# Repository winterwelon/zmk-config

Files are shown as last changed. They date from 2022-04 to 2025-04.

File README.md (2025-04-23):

<p align="center">
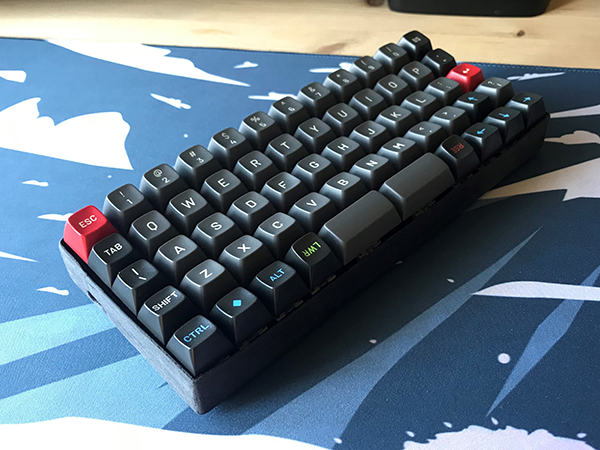
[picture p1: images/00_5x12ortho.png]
  
</p>

# Quick Summary

- :heavy_check_mark: 5x12 Ortholinear Keyboard
- :heavy_check_mark: Hotswappable
- :heavy_check_mark: Modular Spacebar 1x4u (57 keys) or 2x2u (58 keys)
- :heavy_check_mark: Wireless Bluetooth /w nice!nano running ZMK firmware

## Why?

I'm a clumsy man and I often hit the corner of my [96% keyboard](https://www.keychron.com/collections/96-layout-keyboards/products/keychron-k4-wireless-mechanical-keyboard-version-2) when I move my mouse.

So instead of doing the sensible thing and getting a TKL or smaller keyboard, I took the nuclear option of going straight into ortholinear keyboards (because I wanted one and to be honest, they look cool). 

There was a problem though. 

Of all the current 5x12 ortholinear keyboards on the market, I couldn't find one that was a) wireless and b) using a 1x4u spacebar or 2x2u spacebar setup. 

Either I wait for someone to make and sell it or I build it myself.

So... here I am, learning how to make it from the ground up over the course of a few months with no knowledge of pcb design and keyboard form factors. 

Here are some of the steps I've taken to make it.

#### PCB Design
- USB port on the left since it couldn't fit on the top
- Added a reset switch into the board for quick firmware flashing
<table>
  <tr>
    <td>Schematic</td>
     <td>Trace Routing</td>
  </tr>
  <tr>
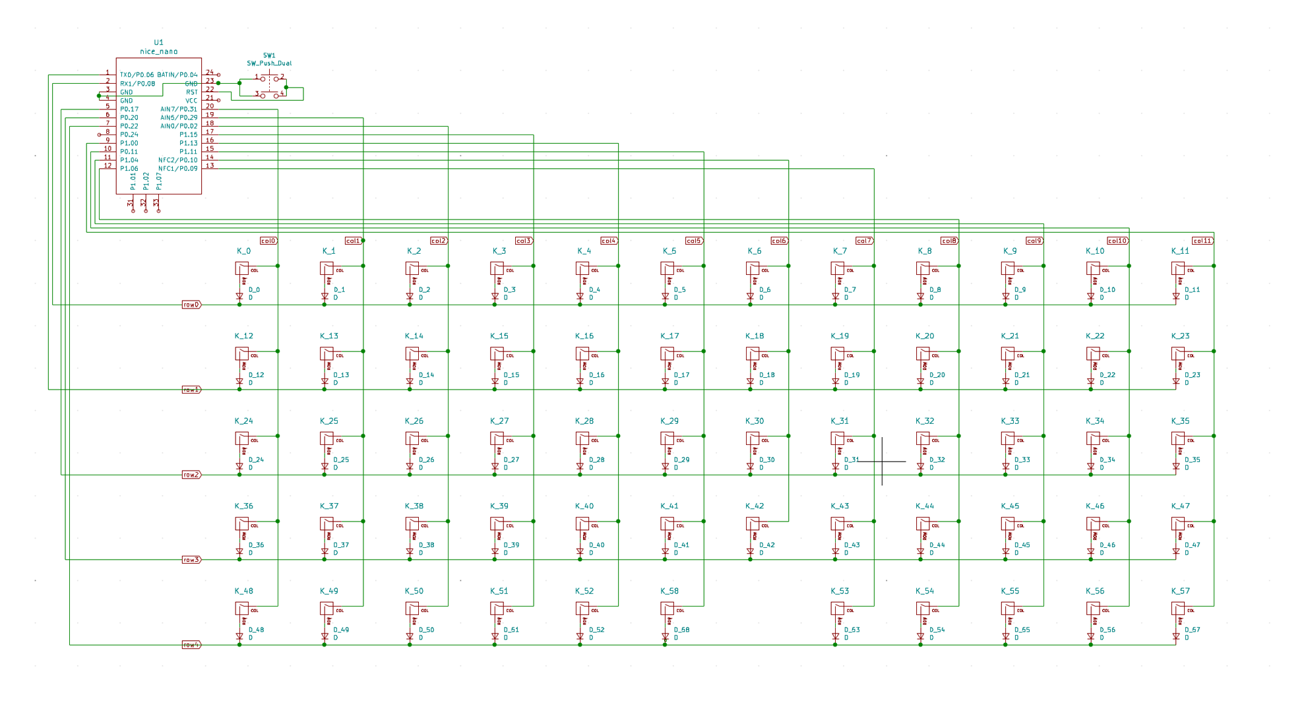
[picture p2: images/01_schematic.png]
    <td>
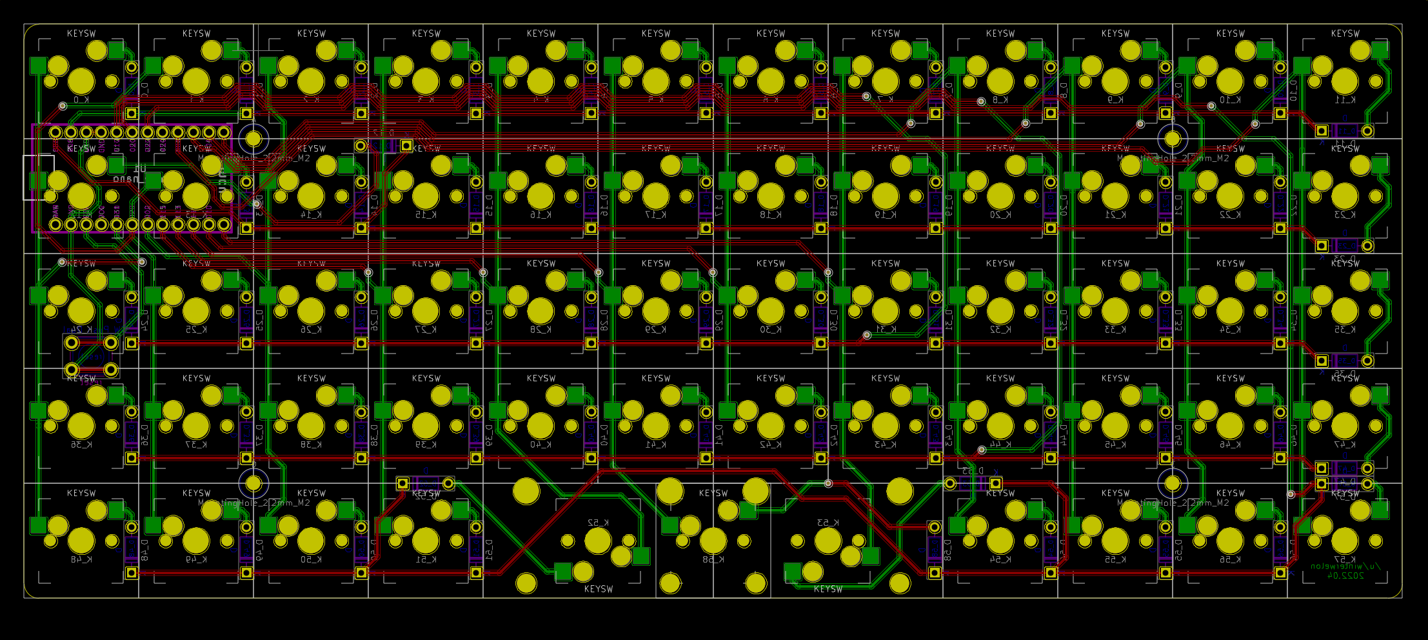
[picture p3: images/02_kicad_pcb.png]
    <td>
  </tr>
 </table>

<table>
  <tr>
    <td>PCB Front</td>
     <td>PCB Back</td>
  </tr>
  <tr>
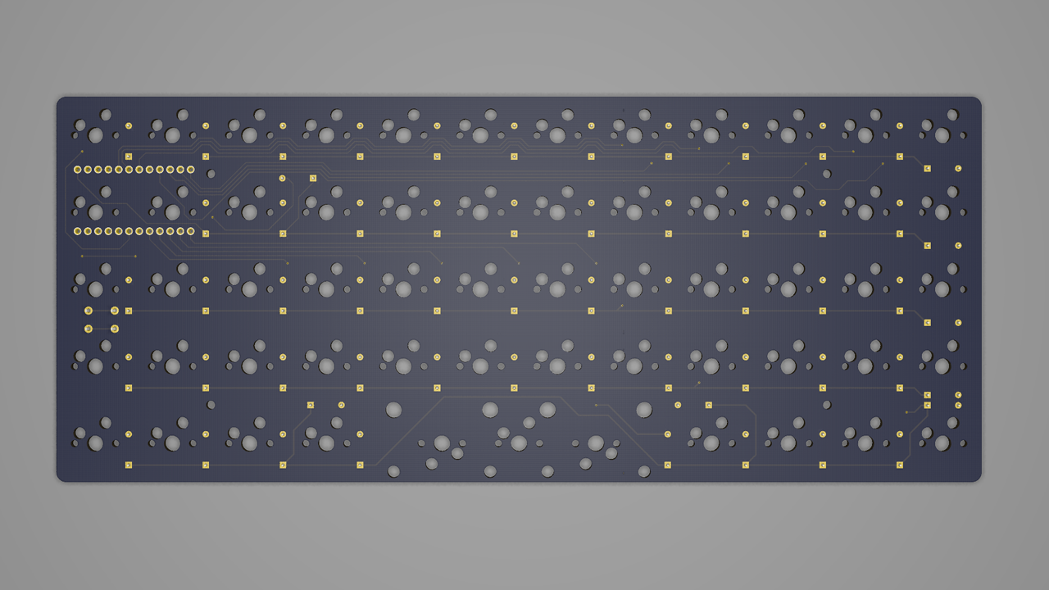
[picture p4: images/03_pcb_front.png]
    <td>
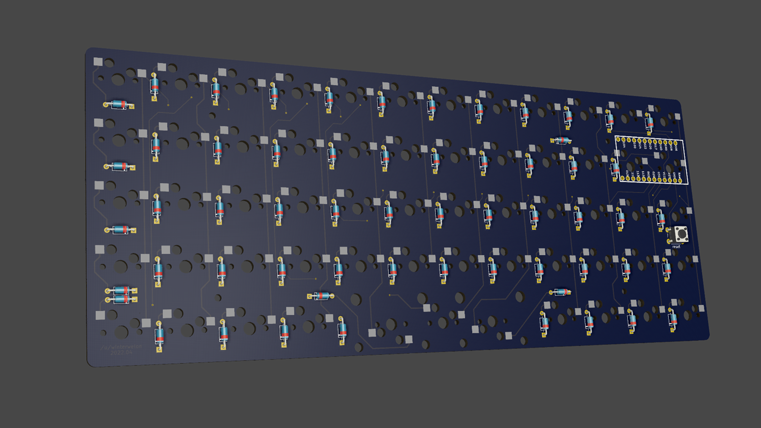
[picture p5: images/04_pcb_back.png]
    <td>
  </tr>
 </table>

<sub><sup>Routing traces is literally playing the Tron Light Cycle game with copper lines instead of bikes.</sup></sub>

#### Top Plate
- 3D Printed with PLA filament at 100% infill
- 4x M2 screws for support

<table>
  <tr>
    <td>4U Spacebar Top Plate</td>
     <td>2x2u Spacebar Top Plate</td>
  </tr>
  <tr>
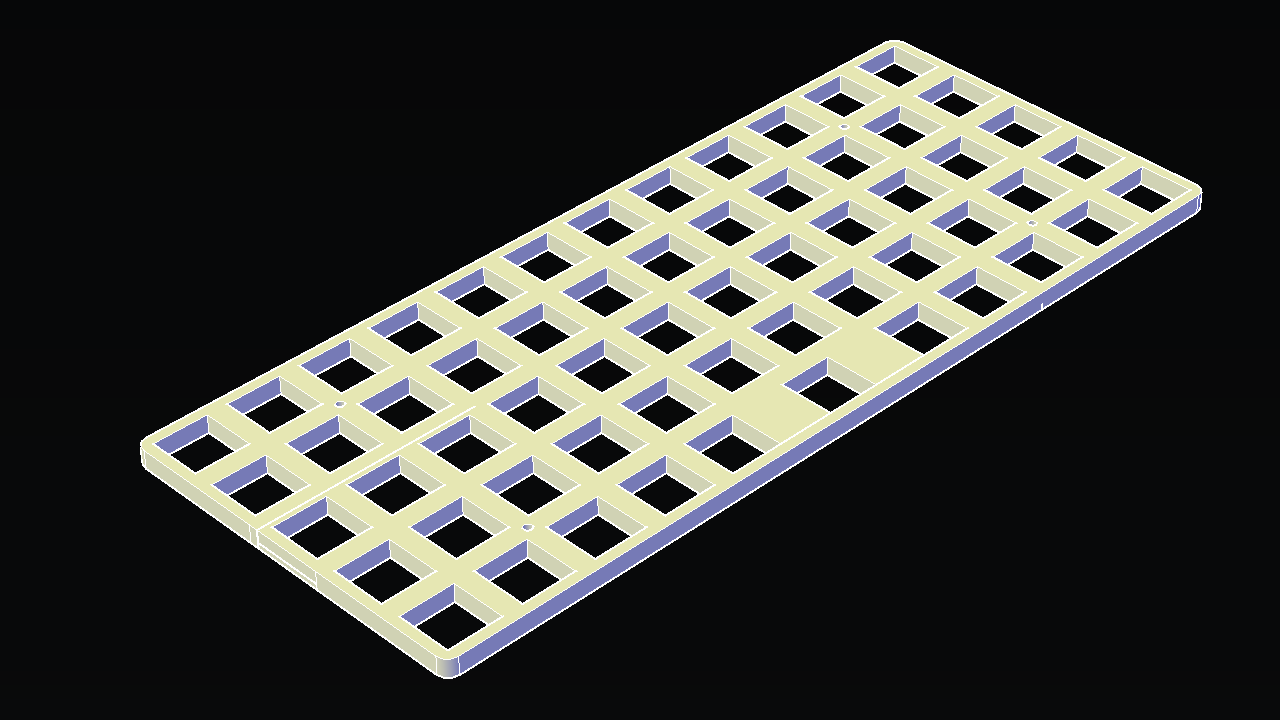
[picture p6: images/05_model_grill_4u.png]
    <td>
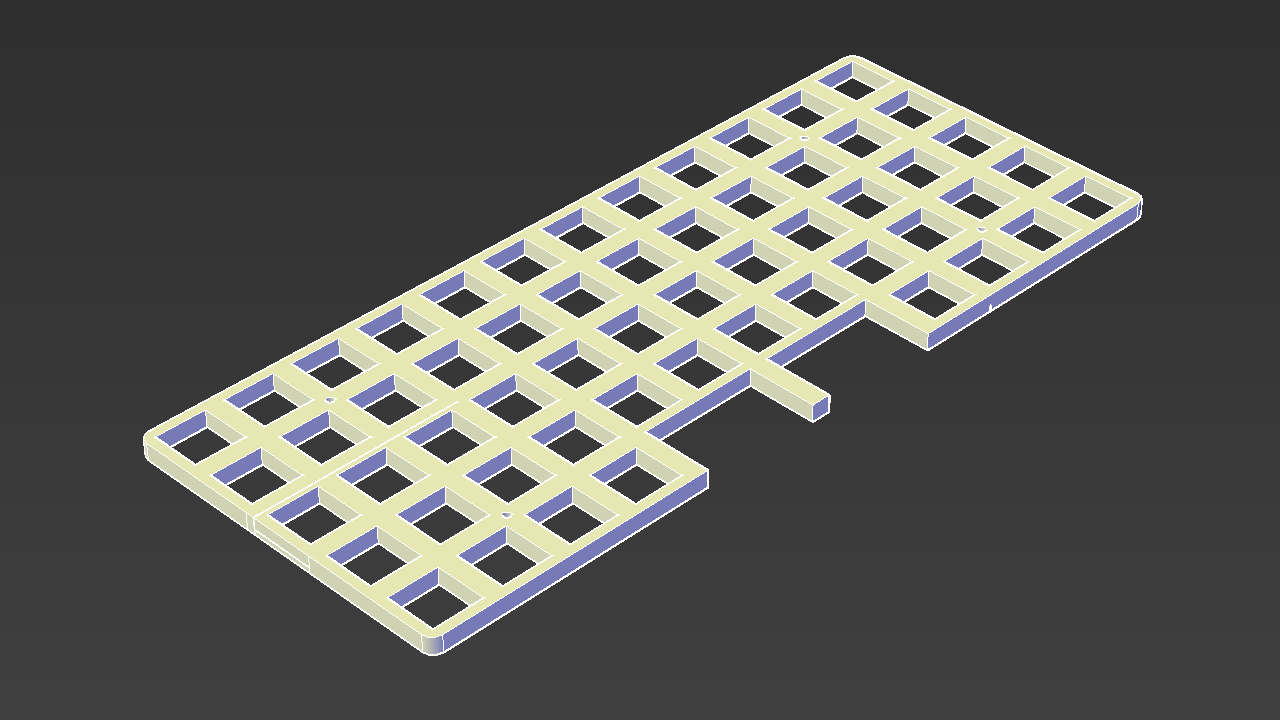
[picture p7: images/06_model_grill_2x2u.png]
    <td>
  </tr>
 </table>

#### Enclosure
- Inclined at a [7° angle](https://matt3o.com/about-mt3-profile-and-devtty-set/) as suggested by the MT3 Profile Creator
- Bezeled inner case to support the PCB
- 3D Printed at 100% infill for structural integrity as well 
- Print time was roughly ~60 hours

<table>
  <tr>
    <td>Top View</td>
     <td>Left View</td>
      <td>Right View</td>
  </tr>
  <tr>
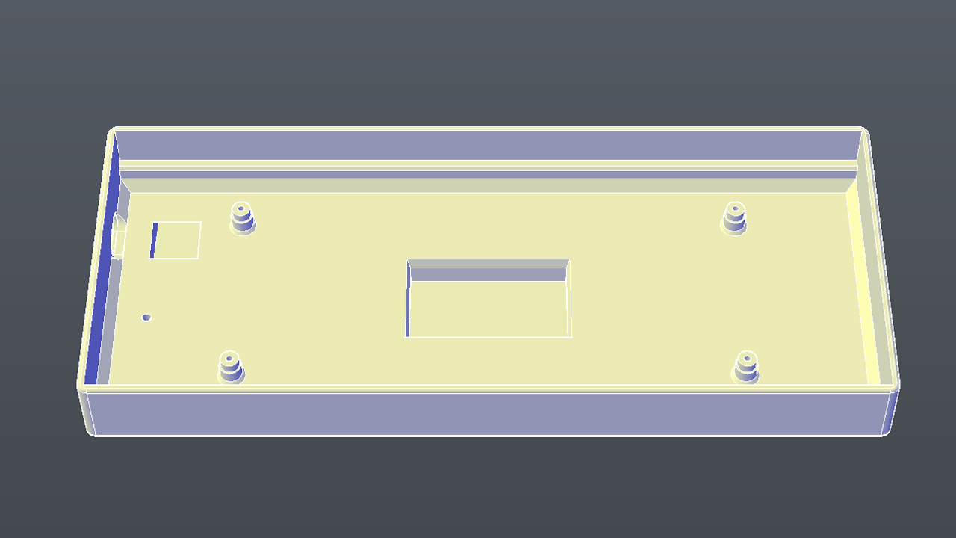
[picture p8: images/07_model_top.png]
    <td>
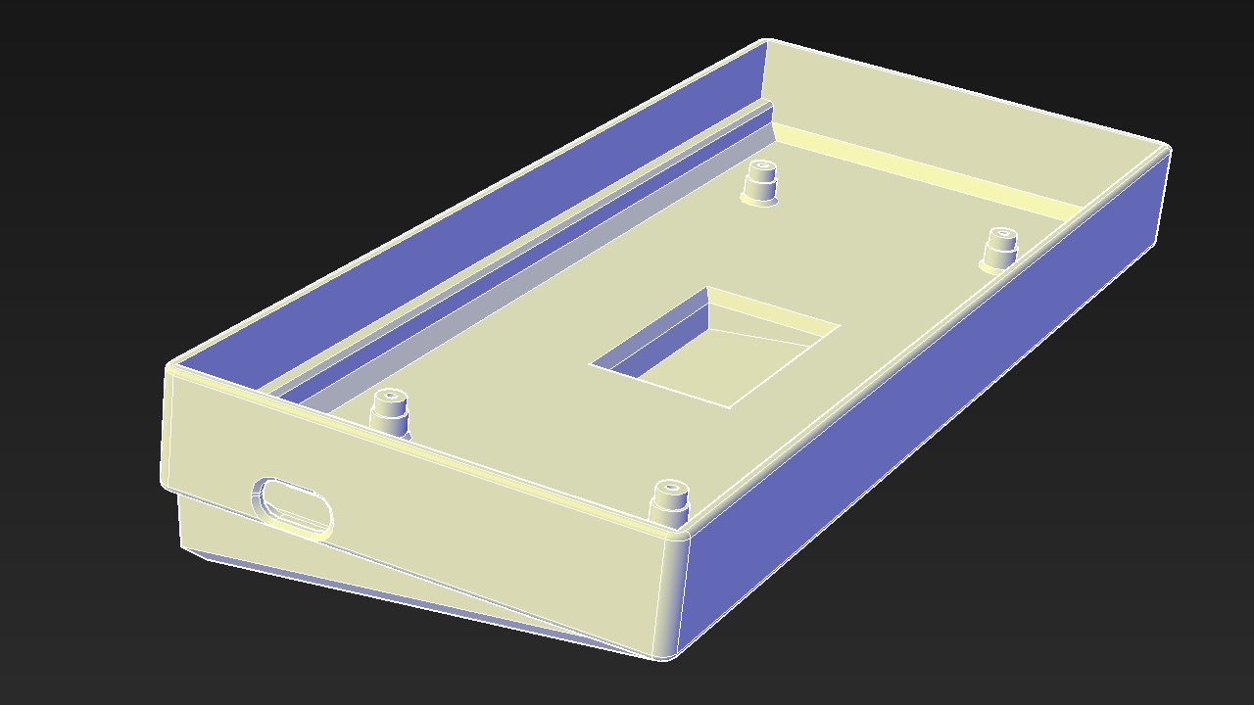
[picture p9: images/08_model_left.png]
    <td>
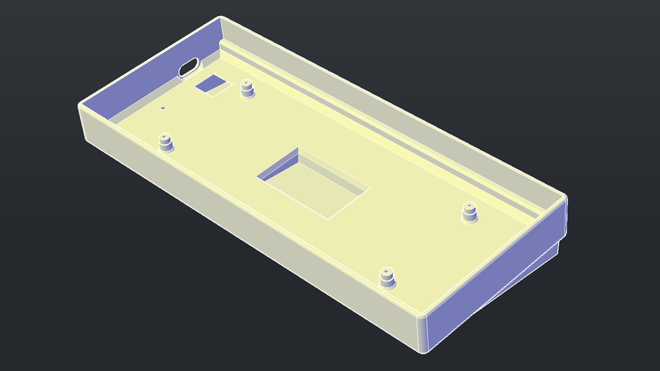
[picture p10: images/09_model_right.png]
    <td>
  </tr>
 </table>

<table>
  <tr>
    <td>Wireframe Right View</td>
     <td>Back View</td>
      <td>Wireframe Back View</td>
       <td>Bottom View w/ hex screwholes & reset port</td>
  </tr>
  <tr>
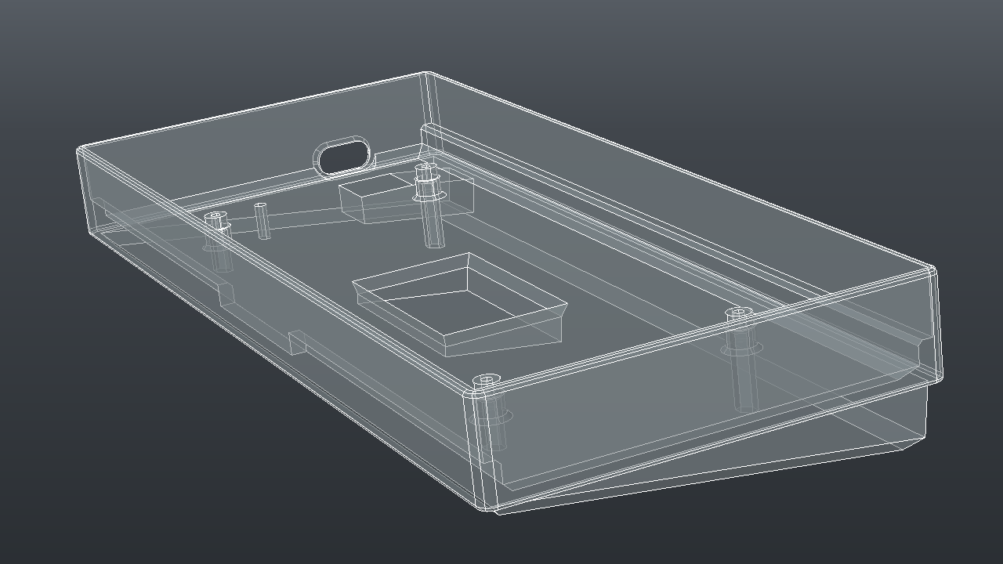
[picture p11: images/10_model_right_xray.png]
    <td>
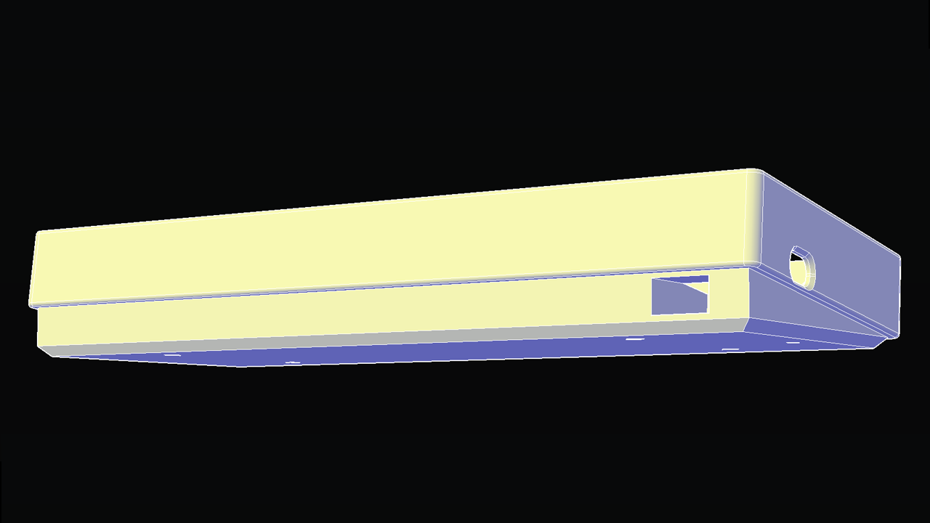
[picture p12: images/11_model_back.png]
    <td>
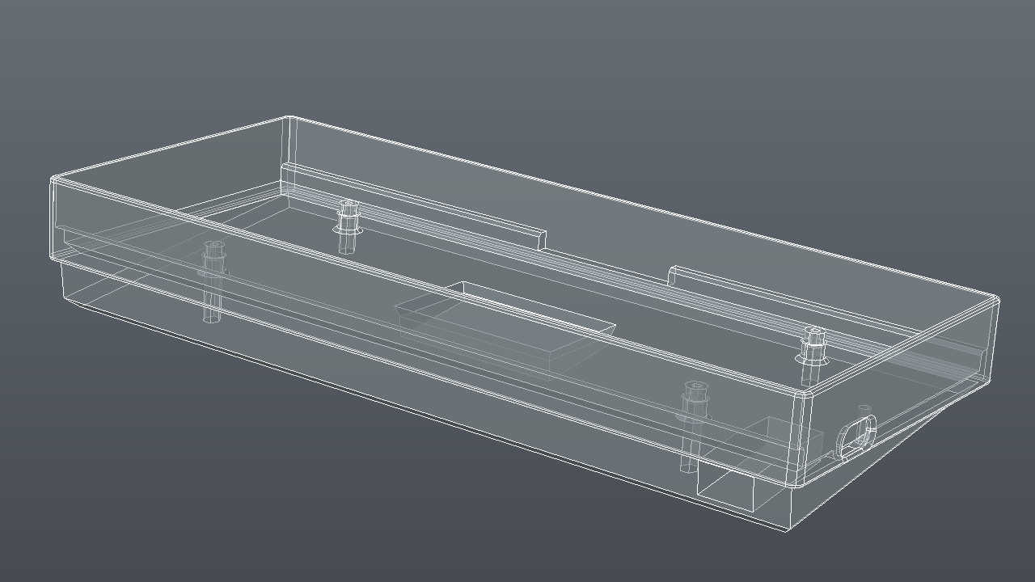
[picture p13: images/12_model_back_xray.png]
    <td>
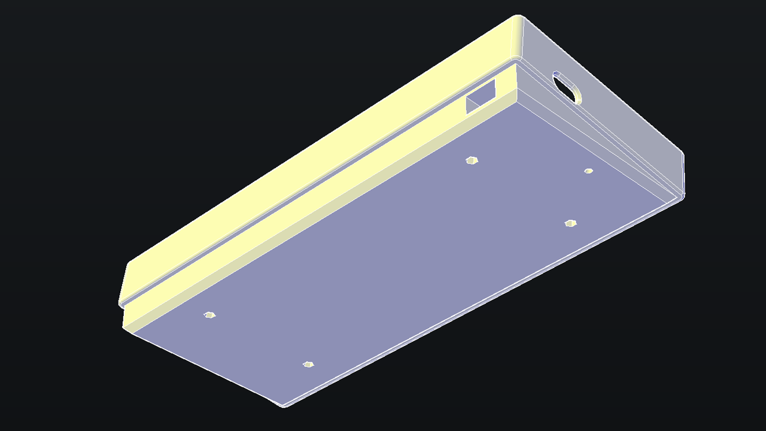
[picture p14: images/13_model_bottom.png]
    <td>
  </tr>
 </table>

#### 5x12 Ortho Build
- Added an on/off switch to quickly manually reset the battery powered MCU
<table>
  <tr>
    <td>Soldering hotwap switches & diodes</td>
     <td>Note scribbles trying to figure out the row & col pinouts</td>
  </tr>
  <tr>
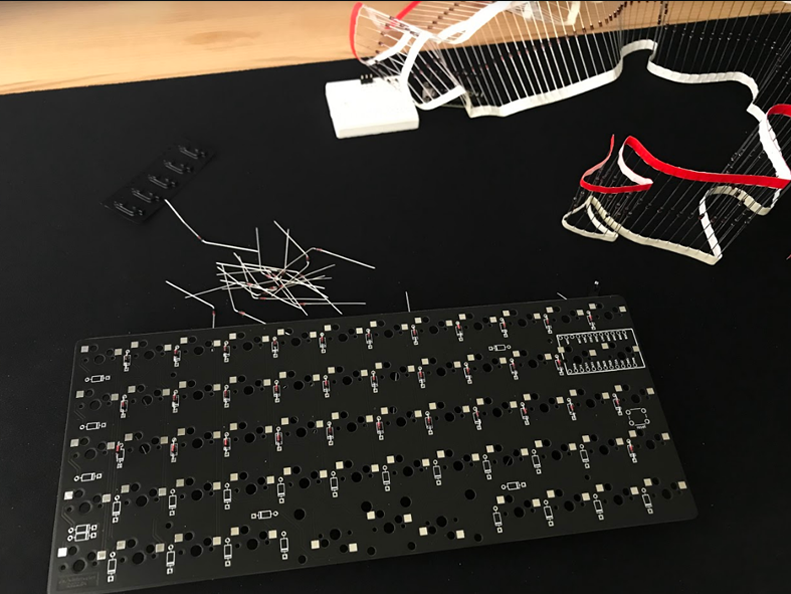
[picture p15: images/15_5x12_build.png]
    <td>
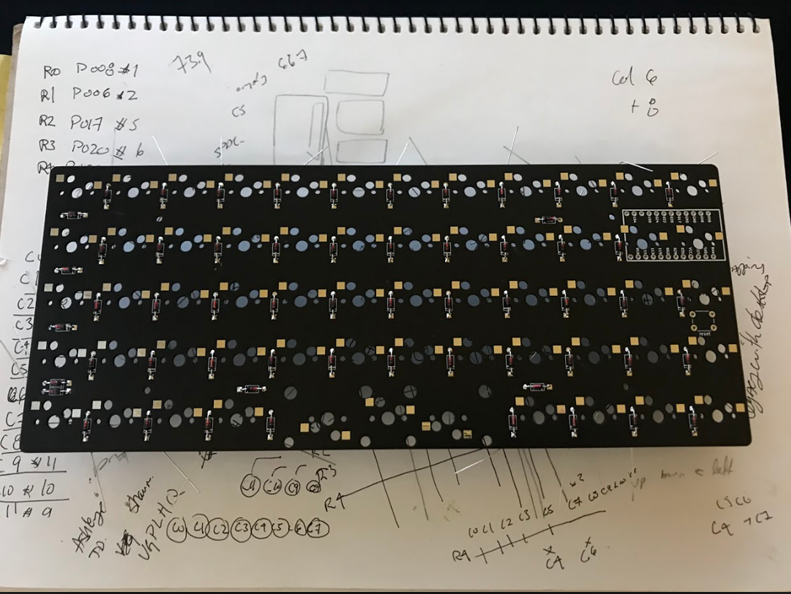
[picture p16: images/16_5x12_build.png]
    <td>
  </tr>
 </table>
 
 <table>
  <tr>
    <td>Assembled Board</td>
     <td>3.7v 350mAh DS 602035 LiPo Battery + Foam Inserts </td>
  </tr>
  <tr>
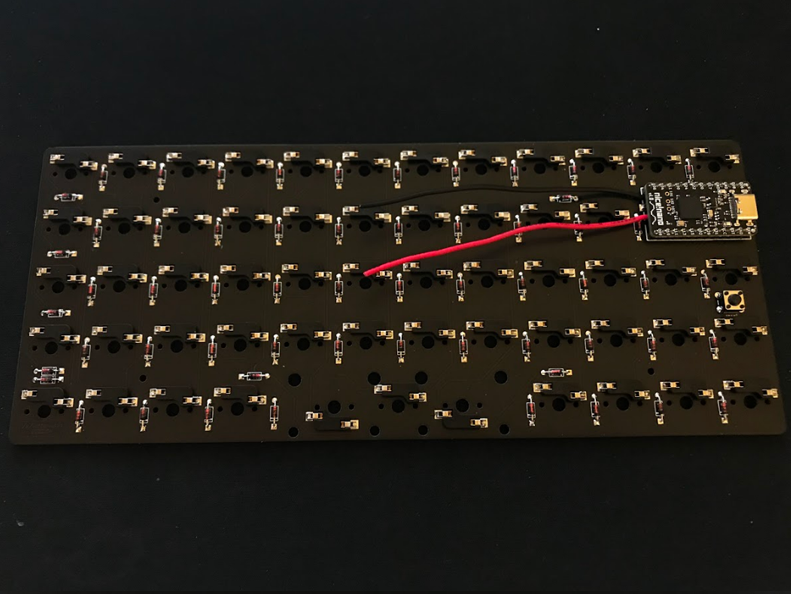
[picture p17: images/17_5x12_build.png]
    <td>
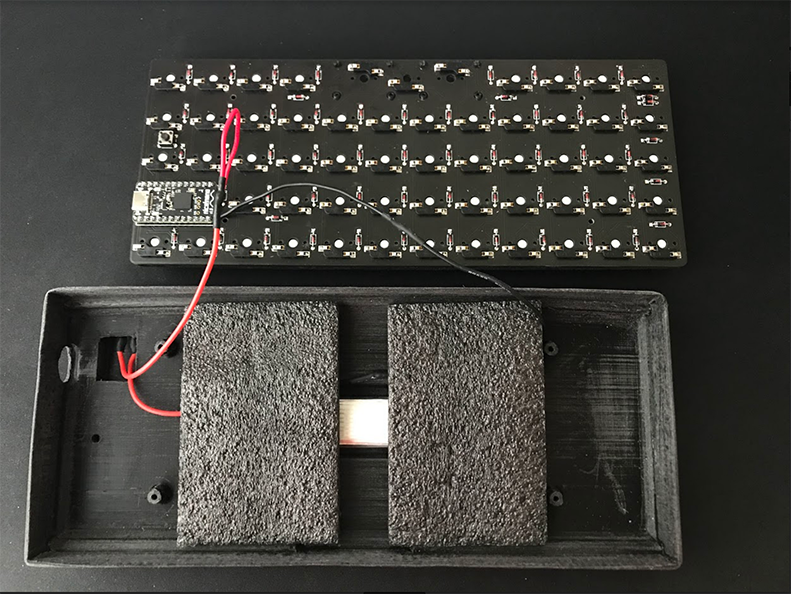
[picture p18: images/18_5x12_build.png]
    <td>
  </tr>
 </table>

#### 4u Spacebar Setup
- Tactile Browns on Alphas, Space & Enter
- Clicky on Modifiers, Arrows and Numerals
<table>
  <tr>
    <td>Box Kailh Switches</td>
     <td></td>
  </tr>
  <tr>
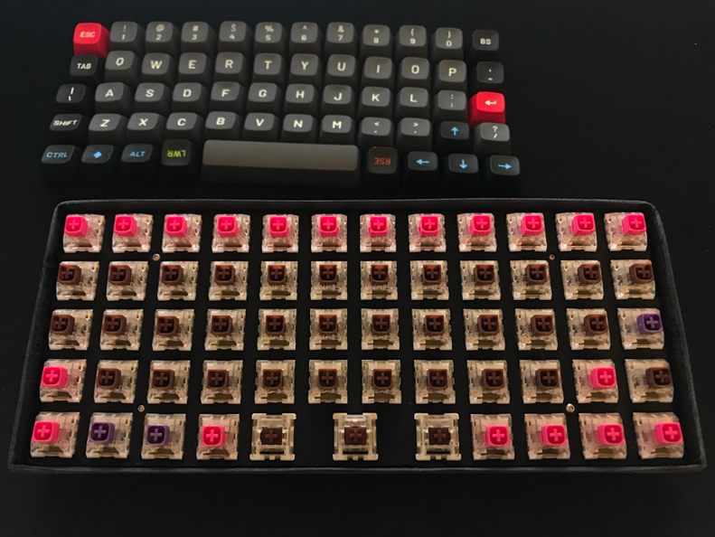
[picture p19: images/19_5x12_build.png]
    <td>
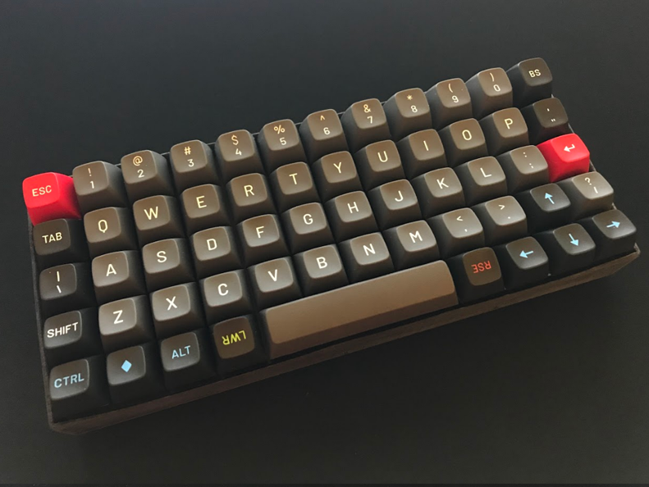
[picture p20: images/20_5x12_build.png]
    <td>
  </tr>
 </table>

#### 2x2u Spacebar Setup

<table>
  <tr>
    <td>Box Brown, Orange, Royal Navy Switches</td>
     <td></td>
  </tr>
  <tr>
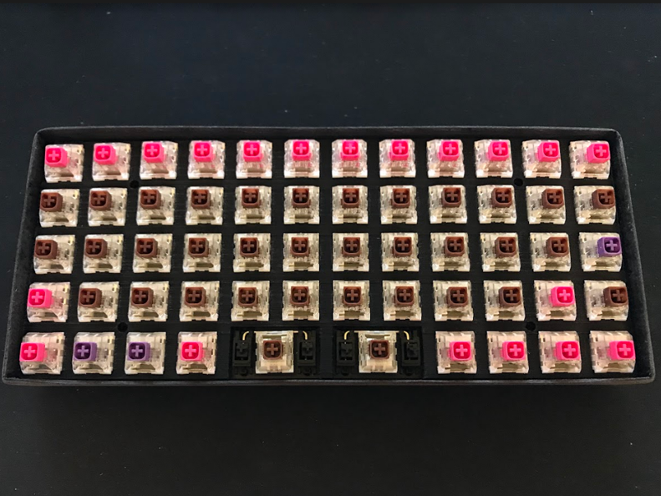
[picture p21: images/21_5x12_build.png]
    <td>
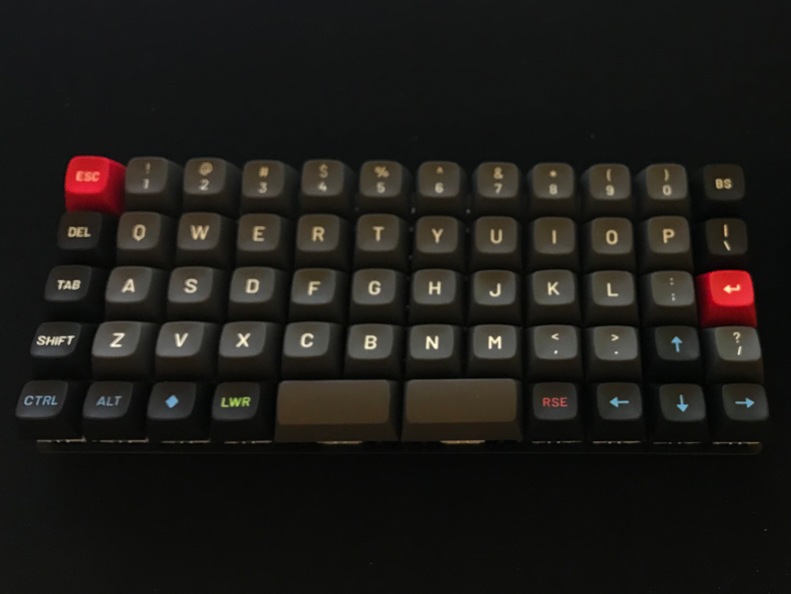
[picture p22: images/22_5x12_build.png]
    <td>
  </tr>
 </table>

## Completed Board \o/
<table>
  <tr>
    <td></td>
     <td></td>
      <td>On/Off Switch for easy access</td>
  </tr>
  <tr>
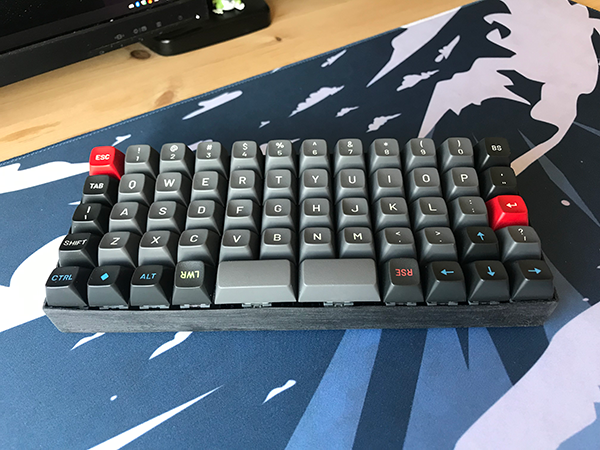
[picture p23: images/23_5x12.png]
    <td>
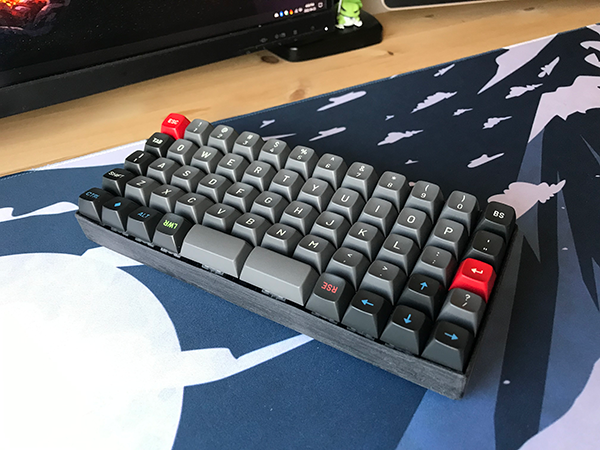
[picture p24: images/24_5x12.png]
    <td>
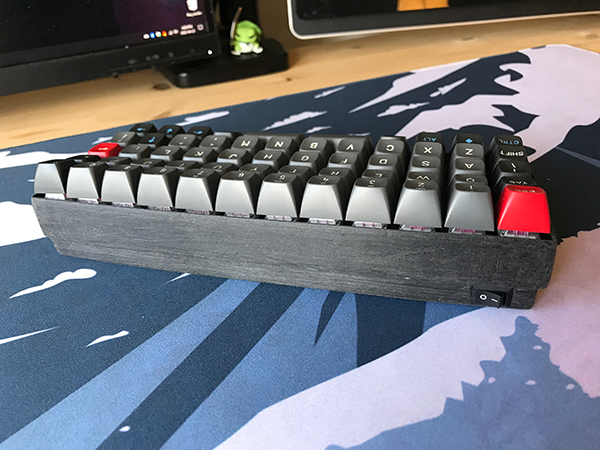
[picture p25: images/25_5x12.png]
    <td>
  </tr>
 </table>

Shoutout to the wiki guides on [/r/MechanicalKeyboards](https://www.reddit.com/r/MechanicalKeyboards/) and the people over @ Nice Keyboards & ZMK for the great tutorials and help.

[current keymapping](/config/boardsource5x12.keymap)

Feedback on 1x4u Spacebar setup 

It isn't perfect or great, would need a custom 4u springboard made to increase rebound sensitivity.
Using 2 additional 1u modified switches does not make it a great spacebar experience.
2x2u spacebar setup is still by far superior in feel and feedback responsiveness. 

Apr.25.23 Update:
Added gerber file for pcb manufacturing.

Apr.23.25 Update:
Added stl model of the kb upon user request.

whoa, the last update date and this update is just the year and the day swapped. 
What an odd timing and cool coincidence. 

<sup><sub>I'm on [reddit](https://www.reddit.com/user/winterwelon).</sup></sub>

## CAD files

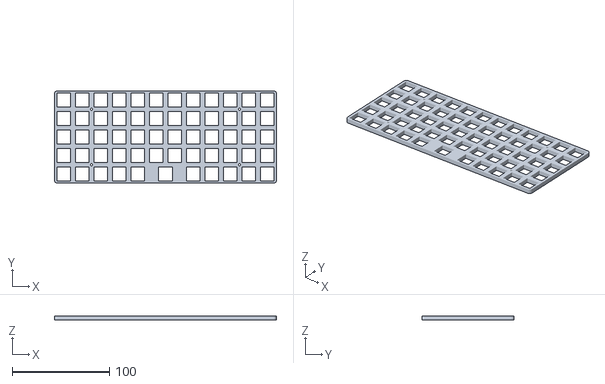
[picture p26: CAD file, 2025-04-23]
ortho5x12_1x4u_grill.stl
228.6 x 95.2 x 4.50

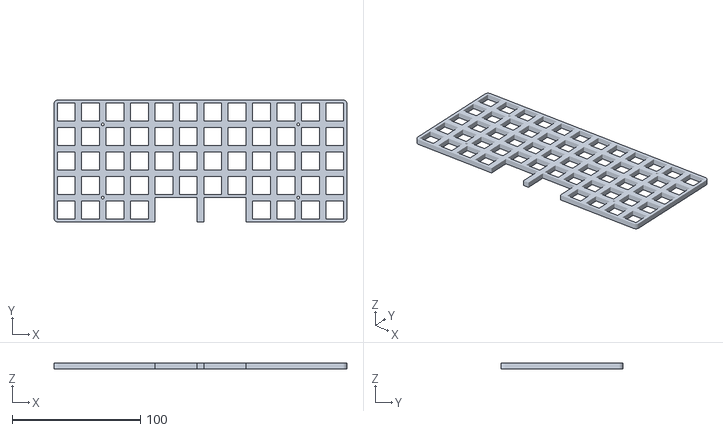
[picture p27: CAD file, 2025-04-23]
ortho5x12_2x2u_grill.stl
228.6 x 95.2 x 4.50

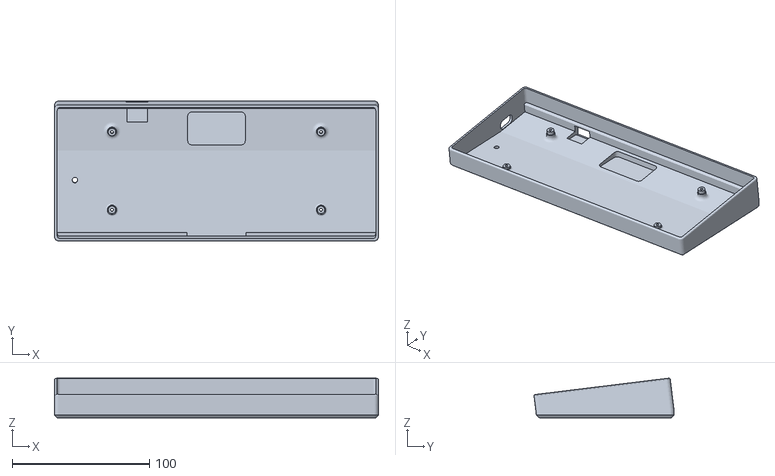
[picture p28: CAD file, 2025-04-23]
ortho5x12_case_final.stl
236.2 x 102.0 x 29.0

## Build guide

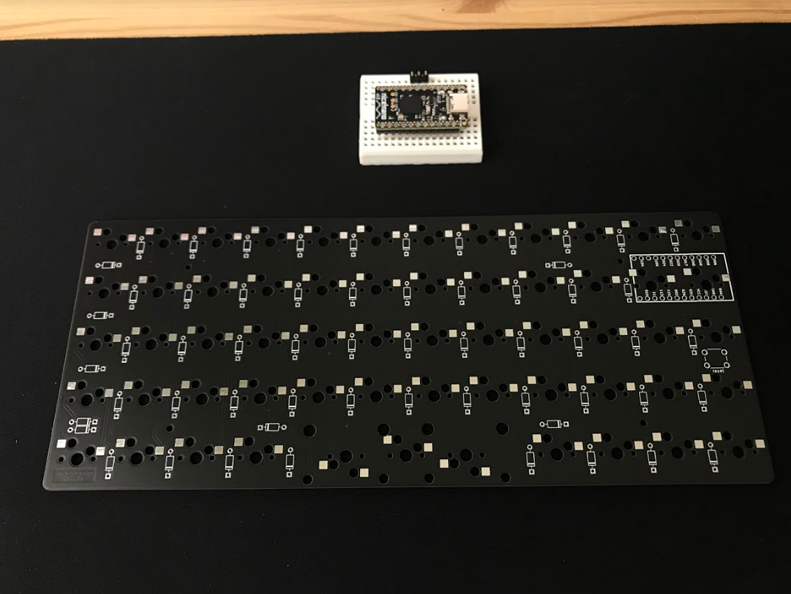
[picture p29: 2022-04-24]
images/14_5x12_build.png

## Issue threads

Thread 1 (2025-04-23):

3d case model

alex-popov-tech, 2025-04-23:
Hello! Awesome keyboard you have there! I wanted to try build one myself, mind sharing 3d models for case? I saw only .png there :(

winterwelon, 2025-04-23:
Hey Alex,

This projet is from 2022, I had to go digging on my old server to see if I still had it.
I can't add the file to this reply, I'll put it on the main page. I hope this works out for you.

Glad you enjoy the prototype I made, I wish you the best in designing and making your own. :)

winterwelon, 2025-04-23:
added. o7

alex-popov-tech, 2025-04-23:
thank you so much! <3

winterwelon, 2025-04-23:
No worries! glad to help :)

Closed 2025-04-23.

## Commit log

2022-04-19 Update boardsource5x12.keymap
    Keymap Update 19.04.2022
2022-04-19 Update boardsource5x12.keymap
    devicetree error: /keymap/lower_layer: undefined node label 'mo2'
    replaced with "&mo 2"
2022-04-19 Update boardsource5x12.keymap
    clean up
    tap-dance functionality test
2022-04-19 Update boardsource5x12.keymap
    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
2022-04-19 Update boardsource5x12.keymap
    Tap Dance Behavior
2022-04-19 Update boardsource5x12.keymap
    Testing tdn1 & tdn2
2022-04-19 Update boardsource5x12.keymap
    row#27; binding cell error
2022-04-19 Update boardsource5x12.keymap
    adjusting tapping speed
2022-04-19 Update boardsource5x12.keymap
    tdn0-9
2022-04-20 Update boardsource5x12.keymap
    added Equal/Minus
    removed CTRL ALT GUI shorcuts
2023-04-24 Add files via upload
    gbr pcb file upload for those that want to manufacture their own
2025-04-23 model of kb case
    added on request of alex, thx!
    [ortho5x12_case_final.stl]
2025-04-23 kb switches grill upload
    keycap grill that goes on top the pcb to support keyboard switches
    - 1x4u for a single 4u spacebar keycap setup
    - 2x2u for two 2u spacebar keycap setup
    [ortho5x12_1x4u_grill.stl, ortho5x12_2x2u_grill.stl]
